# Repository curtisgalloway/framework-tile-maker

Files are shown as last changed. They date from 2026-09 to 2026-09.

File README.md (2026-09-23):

# tilegen



Turn any SVG or image into Framework Desktop front-panel tiles, as multi-color
parts ready to slice. One tile or all 21, with artwork split across the grid.

---

## Use it now

### → **[curtisgalloway.github.io/framework-tile-maker](https://curtisgalloway.github.io/framework-tile-maker/)**

Drop in an SVG or a photo, press **Generate**, download the `.3mf`, open it in
Bambu Studio. Nothing to install, nothing to clone, and nothing is uploaded —
the whole pipeline runs in your browser tab.

[Help and options](https://curtisgalloway.github.io/framework-tile-maker/webjs/help.html)
covers every control.

---

## Running it yourself

Only needed if you want to modify it or work offline:

```bash
git clone --recurse-submodules https://github.com/curtisgalloway/framework-tile-maker.git
cd framework-tile-maker
python3 -m http.server 8790        # any static file server will do
```

Then open <http://127.0.0.1:8790/webjs/>. Cloned without
`--recurse-submodules`? Run `git submodule update --init`.

## What comes out

| File | What it is |
|---|---|
| `NAME.3mf` | Both parts as one object, filaments already assigned. **Use this.** |
| `NAME_body.stl` | Tile with the artwork pocketed out |
| `NAME_ink_1_#RRGGBB.stl` | The insert that fills the pocket exactly |
| `NAME_preview.png` | What the panel surface will look like, before you print |

Body and inserts share the exact same boundary surface — no gap, no overlap.
The two reconstruct the original tile to within 2 × 10⁻⁵ mm³.

---

## Recipes

| Want | Do |
|---|---|
| Logo on one tile | leave the grid at 1 × 1, margin 2.5 |
| One image across the whole panel | click **use it** (3 × 7, margin 0, fit cover) |
| A 2 × 2 block | columns 2, rows 2, fit contain |
| Photo in four colours | pick a JPG, colors 4, fit cover |
| Two-colour logo, one colour as the tile | leave background on `auto` |
| Deeper inlay for white-on-black | depth 1.0 |
| Every tile, even blank ones | leave **blank tile for every empty cell** ticked |

## Options worth knowing

- `--depth 0.6` — inlay depth. 0.6 mm is 3 layers at 0.2 mm, opaque with most
  filaments. Past **1.6 mm** the pocket breaks into the retention hook cut-outs;
  the tool warns you.
- `--background auto` — the color around the outside of the artwork becomes
  the bare tile body instead of a printed color. Saves a filament and all its
  purge. Works for SVGs as well as images: a two-colour logo on a full-bleed
  backdrop prints as a tile in the backdrop colour with one inlaid colour on
  it, rather than two inlays. `--background none` to print it anyway, or
  `--background '#ffffff'` to name it. It never drops the only colour in the
  artwork.
- `--colors N` — how many colors to quantize an image to. Region 1 becomes
  filament 2, region 2 becomes filament 3, and so on.
- `--fit contain | cover | stretch` — `contain` fits the whole artwork inside
  the grid, `cover` fills the grid and crops, `stretch` distorts to fit.
- `--margin` — keep-out from each tile edge. Use `0` for multi-tile artwork so
  it runs across the seams; use `2` or `3` for a single centered logo.
- `--nozzle 0.4` — drives the thin-feature warnings.
- `--min-gap 0.6` — widens any body-colored gap narrower than this by trimming
  the ink beside it; wider gaps are untouched, `0` turns it off. Set it to your
  slicer's first-layer line width plus a little: the art prints face down, so
  every gap is on the first layer, and one narrower than a line fills with ink.
- `--base blank|horizontal|cross|grid|frame` — which tile base to carve into.
  `blank` is the solid face and the default. The others have **open faces**:
  artwork over an opening has no material to carve, so it does not print
  there, and what remains is split into one fragment per opening (28 of them
  for the example logo on `cross`). That is the effect you are asking for, but
  fragments narrower than the mesh tolerance can come out non-watertight —
  slice-check before a long print.
- `--mirror` — only if you print the tile face-up. See *Orientation* below.
- `--embed-filaments` — write the colors into the 3MF, so the slicer opens
  with them assigned instead of bare slot numbers. Ink colors come from the
  artwork. Pair with `--body-color '#2f2f31'` to name the spool you'll load
  for the tile body (filament 1), and `--filament-type PETG` to record the
  material. Off by default: it adds a `project_settings.config`, which is
  project-scoped, so the default output stays exactly as it was.

---

## Printing on the H2D

- **Print face down.** The model already sits that way: the decorated face is
  at z=0, the retention hooks rise in +z. The artwork lands in the first few
  layers against the build plate, which gives the crispest color boundary and
  a smooth finish.
- **Two colors, two nozzles.** Assign body and ink to separate nozzles and the
  H2D swaps without a purge tower. Three or more colors pulls from an AMS and
  purges normally.
- **Body is filament 1.** Inks are 2, 3, 4… in the order printed in the console.
- The tile is 28.5 mm square; 21 of them fit a 256 mm plate in one go.

---

## Why these numbers

- **Pitch 28.60 mm.** Measured from Framework's own released CAD
  (`Tiles/fw_desktop_front_cover.stl`): the tile openings step by exactly 28.60
  in both axes. Several community projects use 28.5, which drifts ~0.6 mm over
  seven rows. Override with `--pitch`.
- **The whole tile face is visible.** At the depth where the tile face sits, the
  cover has no material anywhere across the grid — the 20.9 mm openings deeper
  in are for the retention hooks, not a window over the face. Adjacent tiles
  meet with a ~0.15 mm seam, so artwork runs across tile boundaries nearly
  unbroken.
- **Orientation.** The decorated face is seen from −z, where screen-right is −X
  and screen-down is −Y. That makes the image-to-tile mapping a 180° rotation,
  not a mirror, so artwork is never reversed. Verified by sectioning the
  finished mesh and rendering it from outside.
- **One color, one filament, across every tile.** A tile only carries the
  colors whose artwork reaches it, so the filament slot has to be assigned
  from the full color list before tiles are cut, not from what each tile
  happens to contain. Numbering per tile makes three different colors all come
  out as filament 2 and a three-color panel slices as one color, silently.
  the test suite prints three colored bands across a 3 × 1 grid and asserts
  distinct colors get distinct filaments.
- **Fill rule.** SVG `fill-rule="nonzero"` is honored by computing winding
  numbers, not approximated with even-odd. Get this wrong and counters — the
  inside of an "o", the eye of a spiral — fill in solid. Checked against a
  reference render at IoU 0.996.
- **The artwork canvas is not `cols x pitch`.** Outer tiles contribute only
  their face, and every tile loses `margin` at each edge, so the canvas is
  `(cols-1)*pitch + face - 2*margin`. Sizing to `cols*pitch` overscales by
  `(pitch - face) + 2*margin` and silently crops the artwork — at `--margin 2.5`
  on a single tile that is 18%. The tool reports any real crop.

---

## Credits

**`tile_base.scad` is the work of Marcin Raczkowski (Marmot.Tech)**, licensed
**CC BY-SA 4.0**, from <https://github.com/jermicide/desktoptiles>. No copy of
it lives in this repository — it is vendored unmodified as a git submodule at
`vendor/desktoptiles`, pinned to an upstream commit. All tile body geometry —
the frame, the retention hooks, the constraints, the raised edges, the hook
cut-outs that make the slicer build proper walls — is his. `tilegen` only adds
artwork to it.

His tile follows Framework's published spec,
[`FRAMEWORK_DESKTOP_BLANK_TILE_V0.pdf`](https://github.com/FrameworkComputer/Framework-Desktop/blob/main/Tiles/),
and the panel pitch used here was measured from Framework's
`Tiles/fw_desktop_front_cover.stl` in the same repository.

**Because `tile_base.scad` is CC BY-SA 4.0, tiles produced by this tool are
derivative works.** If you publish or share them, credit Marmot.Tech and
license alike.

---

## Licensing

Two licenses apply here, to different things. The short version: **the code is
Apache 2.0, the tile geometry is CC BY-SA 4.0, and anything you print carries
the CC BY-SA obligations.**

| | License | Why |
|---|---|---|
| `webjs/`, `bases/render.sh` | Apache 2.0 | Original work, © 2026 Curtis Galloway |
| `vendor/desktoptiles/` | CC BY-SA 4.0 | Marcin Raczkowski's repo, vendored as a submodule. Not ours, and not copied into this one |
| `assets/tile_base.stl` | CC BY-SA 4.0 | A render *of* his `tile_base.scad`, so it inherits his license |
| `examples/*.stl`, `examples/*.3mf` | CC BY-SA 4.0 | Same — they contain his tile body |
| **Tiles you generate** | **CC BY-SA 4.0** | Every tile embeds his frame, hooks and constraints |

### What that means in practice

**Using the tool, keeping the tiles to yourself:** nothing to do.

**Publishing or selling tiles you generated** — on Printables, MakerWorld, Etsy,
anywhere: they are derivative works of `tile_base.scad`, so CC BY-SA 4.0
requires you to

1. credit **Marcin Raczkowski (Marmot.Tech)** and link
   <https://github.com/jermicide/desktoptiles>,
2. license the tiles themselves under CC BY-SA 4.0, and
3. say the work was modified.

The [help page](https://curtisgalloway.github.io/framework-tile-maker/webjs/help.html#credits) has text you can paste.

**Reusing tilegen's code** in your own project: Apache 2.0, so keep the notice
and go ahead. Note that Apache 2.0 covers only the code — the moment your
project renders a tile, the output is CC BY-SA again.

**Why not one license for everything?** Apache 2.0 and CC BY-SA 4.0 are not
compatible in either direction, so they cannot be merged — the tile base could
not be relicensed Apache even in principle, since it isn't ours to relicense.
Keeping them separate is what makes the boundary honest: the submodule means
his file is never copied here, and the table above says exactly which artifacts
inherit which terms. `NOTICE.md` records the same thing in one place.

---

## How it is tested

`webjs/tests/run.py` runs 48 checks in headless Chrome against the real
modules — no mocks, no reimplementation. It needs Python only as a process
launcher; there are no third-party packages at all.

The strongest checks are invariants rather than comparisons: body and ink must
reconstruct the base tile to within 2 × 10⁻⁵ mm³, every mesh must be
watertight, each colour must hold one filament slot across every tile, and the
thin-feature warnings must fire on artwork below the nozzle and stay quiet
above it.

The recorded per-tile volumes in `webjs/tests/expected.json` were derived from
a Python implementation that used to live in this repo, and are kept as a
frozen regression snapshot. See `webjs/tests/README.md`.

## The preview shows the real surface

`NAME_preview.png` is drawn from the actual base mesh, not a square: the face
is sliced just above z=0, so the openings in `grid`, `cross`, `horizontal` and
`frame` appear as openings, and artwork is clipped to the material that is
really there. On an open-faced base you can see at a glance which parts of
your artwork survive and which fall into a gap and never print.

## Tile bases

| `--base` | Face | Volume |
|---|---|---|
| `blank` | solid | 1967.63 mm³ |
| `grid` | crossed stripes | 1688.94 mm³ |
| `cross` | diagonal stripes | 1451.97 mm³ |
| `horizontal` | horizontal stripes | 1438.11 mm³ |
| `frame` | none — border only | 1028.20 mm³ |

All five are watertight closed solids, and the test suite checks that, their
dimensions, and that body + ink still reconstructs whichever base was chosen.

They are built by `bases/tilegen_bases.scad`, which `include`s the vendored
`tile_base.scad` unmodified and composes its modules — the extension point
that file's own usage comment documents. Two things made a wrapper necessary
rather than just passing `tile_type`:

- **`tile_base.scad`'s own `crosshatch_fill` clips its stripes to exactly
  `inner_size`**, the same square the frame's inner edge sits on. At angle 0
  the stripes meet that edge squarely and the union is clean; at any other
  angle the slanted ends graze the frame corners with zero-area contact and
  OpenSCAD emits a non-manifold mesh — under *both* backends, at every hatch
  angle and thickness tried. The wrapper runs the stripes past `inner_size` so
  they meet the frame volumetrically.
- **The hook cut-outs are themselves at 45° + 90n.** Stripes at 45° are
  coplanar with the faces being subtracted, which is non-manifold again.
  Measured watertight at 30° and 60°, non-manifold at 15°, 22.5°, 45° and
  67.5°, so the stripe angle defaults to 30°.

---

## Regenerating the tile bases

The five base STLs in `assets/` are committed and the app loads them directly,
so you should not need this. It exists so the bases stay derivable from Marcin
Raczkowski's CC BY-SA source rather than being opaque binaries.

```bash
git submodule update --init      # needs the vendored .scad
./bases/render.sh                # needs OpenSCAD on PATH
```

`bases/render.sh` documents the two non-obvious flags: OpenSCAD's default
Manifold backend exports these bases as meshes that do not close into solids,
so CGAL is requested explicitly; and the stripe angle avoids 45°, where the
stripes go coplanar with the hook cut-outs.

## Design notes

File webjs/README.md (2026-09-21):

<!--
SPDX-FileCopyrightText: 2026 Curtis Galloway
SPDX-License-Identifier: Apache-2.0
-->

# tilegen in the browser

The default way to use tilegen: the whole pipeline in a tab, with no Python,
no server and no install. SVG and raster both work.

```bash
python3 -m http.server 8790 --directory ..   # any static server will do
open http://127.0.0.1:8790/webjs/
```

Nothing is uploaded. The page fetches `../assets/tile_base.stl`, pulls
Manifold's WASM from a CDN, and does everything else locally.

## Does it produce the same tiles?

Measured against the Python on `examples/fuchsia.svg`, one tile, margin 2.5:

| | Python | Browser |
|---|---|---|
| body volume | 1849.1714 mm³ | 1849.1506 mm³ (0.0011% off) |
| ink volume | 118.4562 mm³ | 118.4771 mm³ (0.0176% off) |
| both watertight | yes | yes |
| body + ink vs base | +0.000018 mm³ | **+0.000018 mm³** |
| 3MF entries / objects / extruders | 4 / 3 / 1,2 | 4 / 3 / 1,2 |

The reconstruction figure is the one that matters, and it is identical to the
the Python's to every digit its suite printed. The volume deltas are curve
flattening — the browser samples paths through `getPointAtLength`, svgelements
computes them analytically — and 0.02% is orders of magnitude below what a
0.4 mm nozzle resolves.

A 3 × 7 panel produces 21 objects with no missing cells, and the 3MF passes a
CRC check as a zip.

## Why it is so little code

Two things carry it:

- **Manifold ships the same engine as WASM.** `manifold3d` in Python and
  `manifold-3d` on npm are the same C++ project, so the mesh booleans are not
  a reimplementation, they are the same code.
- **`CrossSection` is Clipper2 with fill rules built in.** That replaces both
  shapely *and* a hand-rolled nonzero winding-number partition —
  `new CrossSection(contours, 'NonZero')` is the whole of it.

The browser itself replaces svgelements: every shape is an
`SVGGeometryElement`, so `getPointAtLength` flattens béziers and arcs exactly
as the renderer would, `getComputedStyle` resolves fill through CSS and
inheritance, and `getCTM` bakes in nested transforms.

## What had to be written by hand

- **Subpath splitting** (`svgload.js`). The DOM will not hand back individual
  subpaths, and the fill rule is defined over them — an `o` whose counter is a
  second subpath must arrive as two rings. Hence a path tokenizer.
- **STL welding** (`stl.js`). An STL is a triangle soup; Manifold's
  constructor throws on anything that is not an oriented 2-manifold.
- **Zip** (`threemf.js`). `CompressionStream('deflate-raw')` is exactly what a
  zip entry wants, so this is a CRC table and a few headers, no library.

## Warnings

The thin-feature and crop warnings are ported. They tell you a logo will not
survive the nozzle before you print it, which is the whole point of them.

The reported PERCENTAGES differ from the CLI's by a few points and are not
tuned to match. shapely offsets through GEOS, this goes through Clipper2, and
the miter limit dominates the difference: on the example logo at an
exaggerated 2 mm nozzle, ink loss reads 25.8% at miter limit 2 and 13.1% at
100, against the CLI's 17%. Fitting a limit to match on one input would be
wrong on the next. Both use the same parameter shapely defaults to (5.0), and
at realistic nozzle sizes they agree on the thing that matters -- whether to
warn at all. On a 3x7 panel at 0.4 mm both emit exactly one warning.

## Not ported

- `--rotate`, `--bleed`, `--scale`, `--invert`, `--plate-origin`.
- `--rebuild-base`, which needs OpenSCAD and so is inherently a CLI job.

## Tests

`python3 webjs/tests/run.py` runs 48 checks in headless Chrome against the
real modules. See `webjs/tests/README.md`.

It earned its place on the first run by catching a real bug: `resolveOverlaps`
had never been ported, so quantized raster regions overlapped on their shared
boundary and were extruded twice.

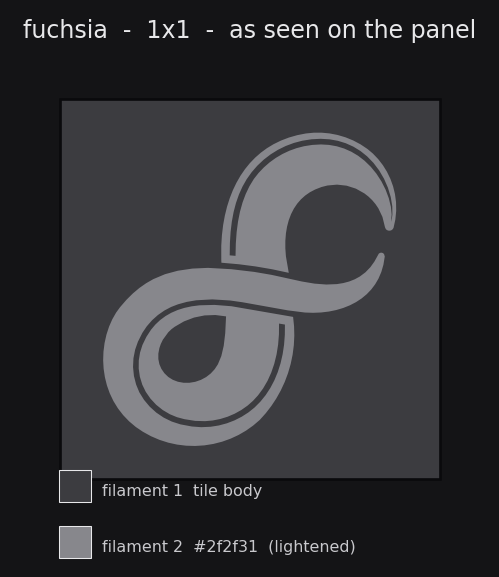
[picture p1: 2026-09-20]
examples/fuchsia_preview.png

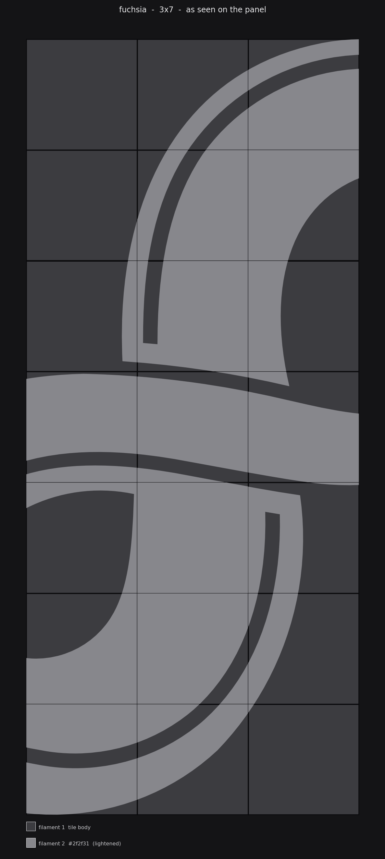
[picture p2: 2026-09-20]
examples/panel_3x7/fuchsia_preview.png

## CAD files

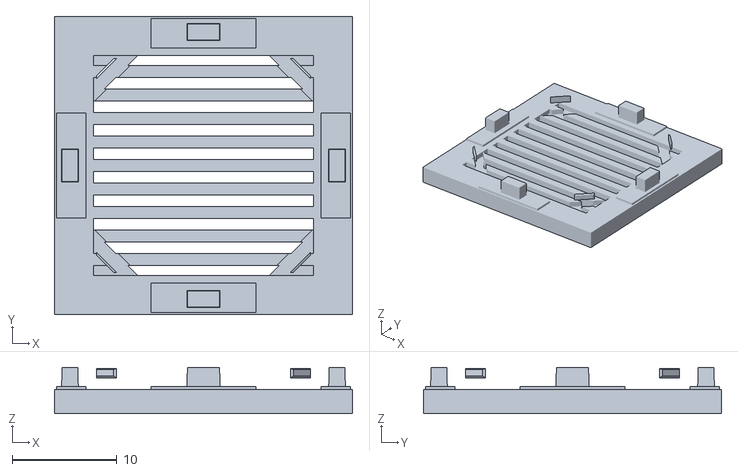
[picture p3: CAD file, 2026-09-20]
assets/tile_base_horizontal.stl
28.5 x 28.5 x 4.40

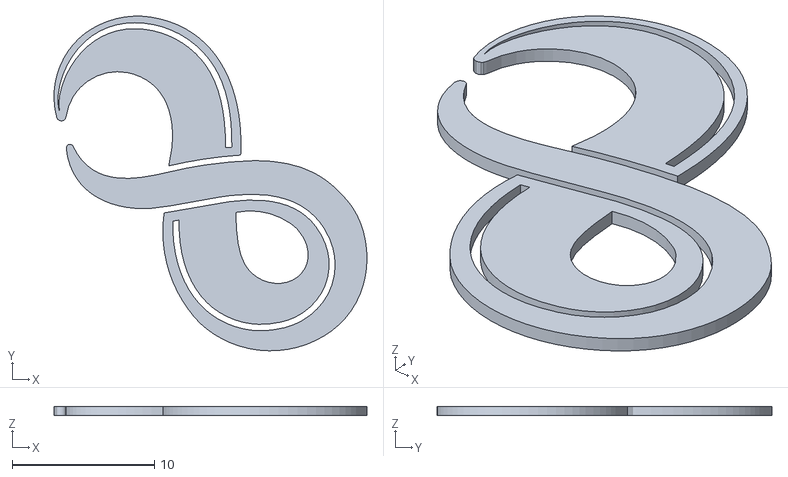
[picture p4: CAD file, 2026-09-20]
examples/fuchsia_ink_1_#2f2f31.stl
22.0 x 23.5 x 0.6

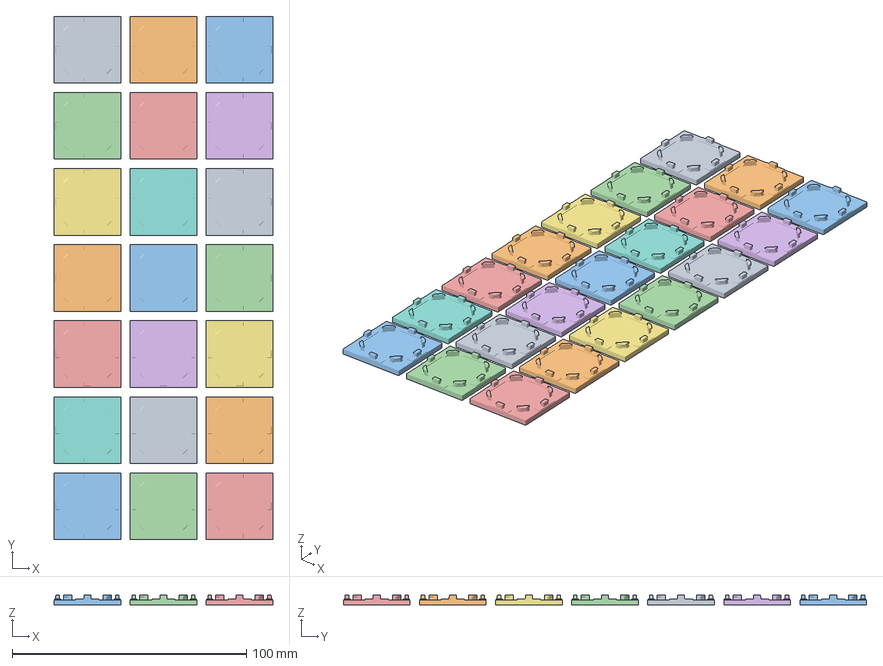
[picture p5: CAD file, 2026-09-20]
examples/panel_3x7/fuchsia_3x7.3mf
93.5 x 223.5 x 4.40 mm
fuchsia_r0c0
fuchsia_r0c1
fuchsia_r0c2
fuchsia_r1c0
fuchsia_r1c1
fuchsia_r1c2
fuchsia_r2c0
fuchsia_r2c1
fuchsia_r2c2
fuchsia_r3c0
fuchsia_r3c1
fuchsia_r3c2
fuchsia_r4c0
fuchsia_r4c1
fuchsia_r4c2
fuchsia_r5c0
fuchsia_r5c1
fuchsia_r5c2
fuchsia_r6c0
fuchsia_r6c1
fuchsia_r6c2

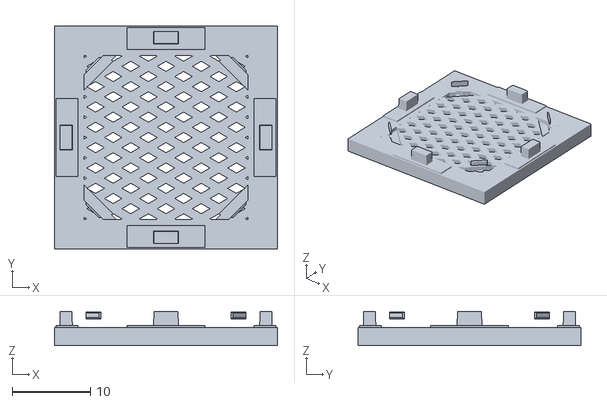
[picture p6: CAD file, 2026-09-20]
assets/tile_base_grid.stl
28.5 x 28.5 x 4.40

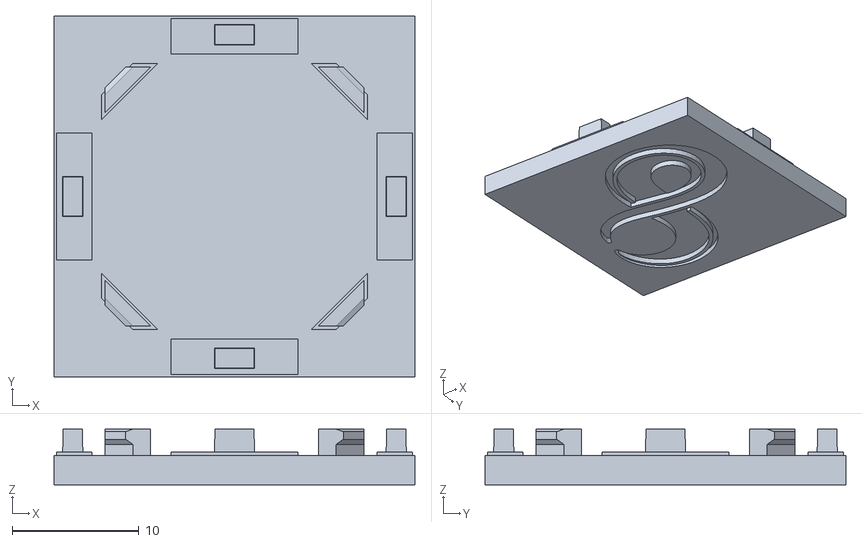
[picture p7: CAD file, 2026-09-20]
examples/fuchsia_body.stl
28.5 x 28.5 x 4.40

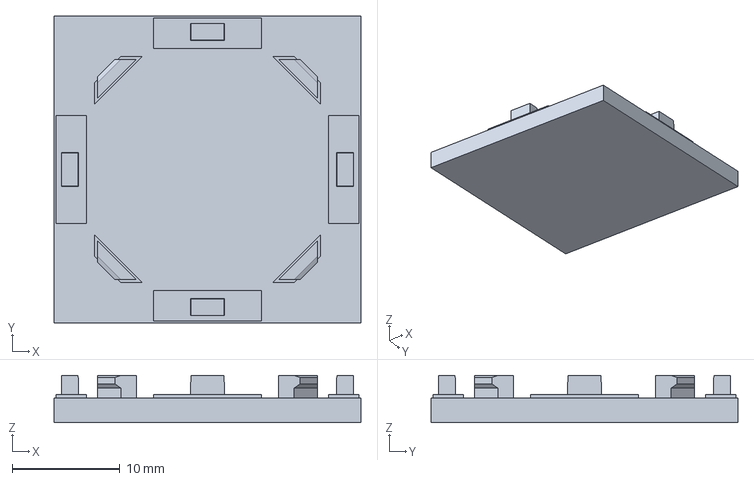
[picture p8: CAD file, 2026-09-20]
examples/fuchsia.3mf
28.5 x 28.5 x 4.40 mm

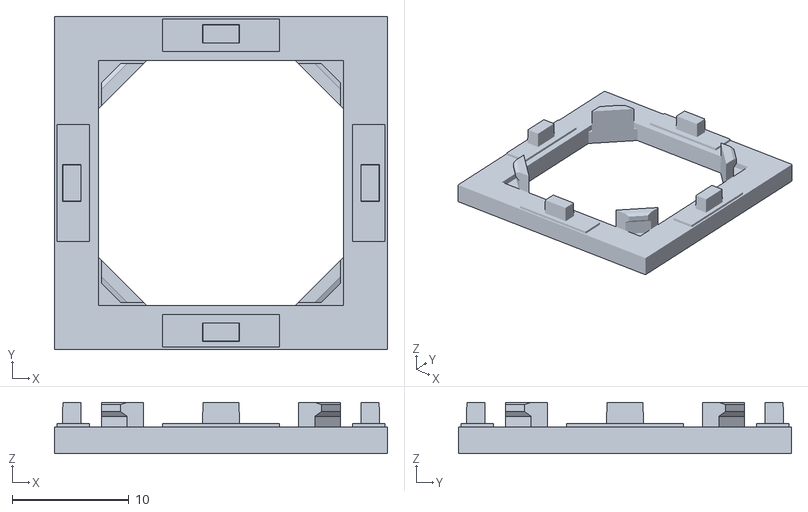
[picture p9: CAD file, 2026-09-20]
assets/tile_base_frame.stl
28.5 x 28.5 x 4.40

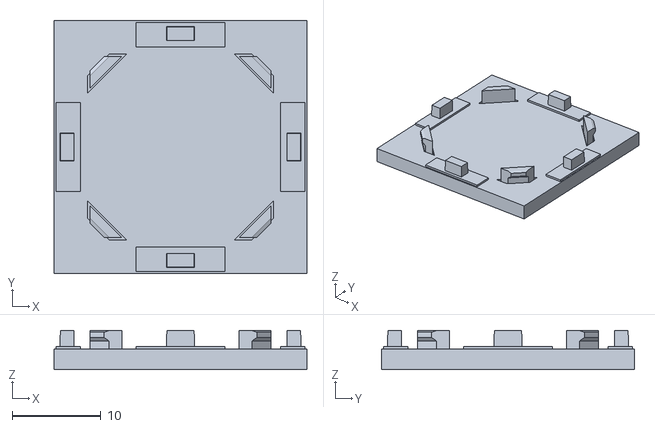
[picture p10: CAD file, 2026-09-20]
assets/tile_base.stl
28.5 x 28.5 x 4.40

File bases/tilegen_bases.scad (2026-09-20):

// SPDX-FileCopyrightText: 2026 Curtis Galloway
// SPDX-License-Identifier: Apache-2.0
//
// Extra tile bases for tilegen, built on Marcin Raczkowski's tile_base.scad
// (CC BY-SA 4.0, vendor/desktoptiles). That file is included unmodified and
// its modules are composed here, which is the extension point its own usage
// comment documents:
//
//     include <tile_base.scad>
//     tile_type = "none";
//     union() { full_frame(); my_design(); }
//
// Rendered tiles remain derivative works of his file -- see NOTICE.md.
//
// Why this file exists at all: tile_base.scad's own crosshatch_fill clips its
// stripes to exactly inner_size, the same square the frame's inner edge sits
// on. At angle 0 the stripes meet that edge squarely and the union is clean,
// but at any other angle the slanted ends graze the frame corners with
// zero-area contact and OpenSCAD emits a non-manifold mesh -- confirmed under
// both the CGAL and Manifold backends, at hatch angles 30/40/44/45/46 and
// thicknesses 0.8 through 2.0. The fix is not a parameter: it is to let the
// stripes run PAST inner_size so they meet the frame volumetrically.

include <../vendor/desktoptiles/tile_base.scad>

// Suppress the included file's own top-level output; we compose it ourselves.
tile_type = "none";

// How far the fill runs into the frame. Anything comfortably larger than a
// rounding error works: the overlap is buried inside frame material, so it
// changes nothing you can see or print.
tg_overlap = 0.5;

/* [tilegen] */
// Which base to render
tg_base = "blank"; // ["blank", "frame", "horizontal", "cross", "grid"]
// Stripe width [mm]
tg_thickness = 1.125;
// Stripe angle [deg]. NOT 45: the hook cut-outs are themselves at 45 + 90n
// degrees, so 45-degree stripes end up coplanar with the faces being
// subtracted and the result is non-manifold. Measured watertight at 30 and 60,
// non-manifold at 15, 22.5, 45 and 67.5.
tg_angle = 30;

module tg_stripes(angle, thickness) {
  span = inner_size + 2 * tg_overlap;
  n = ceil(inner_size / thickness / 2) + 2;
  linear_extrude(front_thickness) intersection() {
    square(span, center = true);
    union() for (i = [-n : n])
      rotate([0, 0, angle])
        translate([0, thickness * 2 * i])
          square([inner_size * 3, thickness], center = true);
  }
}

// The hook cut-outs must be taken out of the finished solid, not out of the
// fill alone: a stripe that now overlaps the frame would otherwise re-fill
// the cut-out the frame just made.
module tg_tile(fill_angle, thickness, striped = true, crossed = false) {
  difference() {
    union() {
      mounts();
      linear_extrude(frame_thickness)
        difference() {
          square(tile_size, center = true);
          square(inner_size, center = true);
        }
      if (striped) {
        tg_stripes(fill_angle, thickness);
        if (crossed) tg_stripes(-fill_angle, thickness);
      }
    }
    hook_cutout();
  }
}

if (tg_base == "blank") {
  blank_tile();
} else if (tg_base == "frame") {
  full_frame();
} else if (tg_base == "horizontal") {
  tg_tile(0, tg_thickness);
} else if (tg_base == "cross") {
  tg_tile(tg_angle, tg_thickness);
} else if (tg_base == "grid") {
  tg_tile(tg_angle, tg_thickness, striped = true, crossed = true);
}

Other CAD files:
assets/tile_base_cross.stl

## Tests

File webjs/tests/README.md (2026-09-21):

<!--
SPDX-FileCopyrightText: 2026 Curtis Galloway
SPDX-License-Identifier: Apache-2.0
-->

# Browser tests

48 regression checks. The browser modules run for real in headless Chrome.

```bash
python3 webjs/tests/run.py              # non-zero exit on failure
python3 webjs/tests/run.py --headed     # watch it in a visible browser
```

stdlib only — no pip install, no npm.

Open `/webjs/tests/` in any browser to run the same suite by hand.

## Why a real browser

The SVG loader uses the browser's own SVG engine on purpose — `getPointAtLength`
flattens curves exactly as the renderer would — and the raster path uses canvas.
jsdom implements neither, so headless Chrome is the only honest harness. The
runner starts a static server, launches Chrome, and the page POSTs its results
back; stdlib only, no npm.

## expected.json is a frozen snapshot

These were derived from the Python reference implementation that used to live
in this repo, and were correct against it when recorded. That implementation
has been removed, so they are now **golden values**: a failure means the
browser's behaviour changed, which is what a regression suite is for — but no
longer that it disagrees with an independent implementation.

Several checks never needed the reference and are the stronger ones: body+ink
reconstructing the base to 0.00002 mm³, watertightness, distinct filament slots
per colour, and whether the thin-feature warnings fire. Those are invariants,
and they would catch a real geometry regression with every recorded number
deleted. It is the per-tile volume comparisons that lost their independence.

## Tolerances, and why they differ

| | Tolerance | Why |
|---|---|---|
| single tile, SVG | 0.05 mm³ | same kernel, same contours; agrees to ~0.02 |
| reconstruction | 0.001 mm³ | exact: a boolean partition cannot drift |
| 3×7 panel | 0.15 mm³ | flattening error scales with artwork size |
| raster, smooth | 1% | recorded against a different tracer; measures 0.03% |
| raster, noise | 8% | see below |

The noise fixture is 160 px of high-frequency speckle. Every blob is a few
pixels across, so marching squares placing its isoline on the half-pixel
boundary shifts a large perimeter relative to a small area, and the two tracers
land ~4.6% apart. That is inherent to the fixture, not a defect — which the
smooth fixture proves by agreeing to 0.03% on the same code path. So the noise
fixture asserts *survival and self-consistency* rather than agreement.

The exact assertion there — body + ink reconstructing the base — is what caught
the missing `resolveOverlaps`: quantized regions are disjoint by pixel, but
their contours are traced independently, so neighbours both claimed the
boundary strip and the overlap was extruded twice (+2.22 mm³). Verified to
still bite: removing `resolveOverlaps` fails that check and only that check.

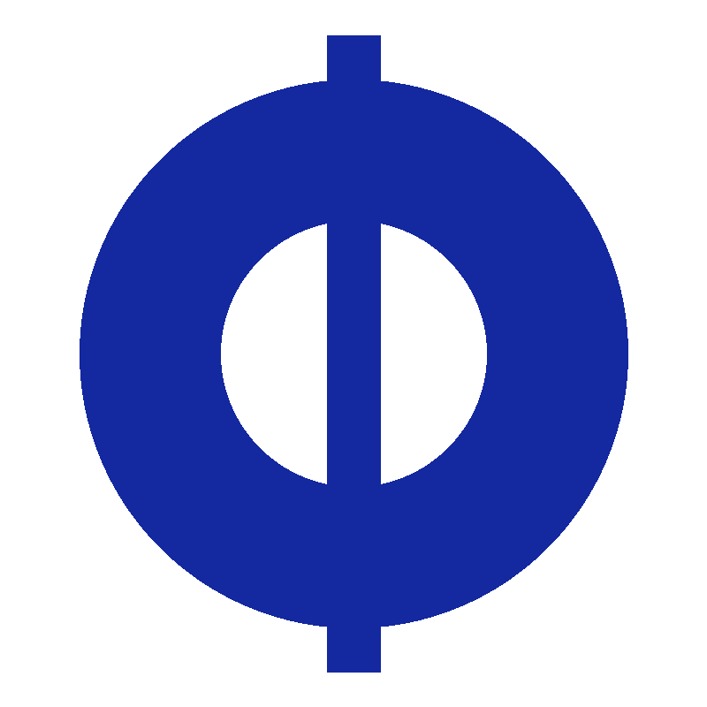
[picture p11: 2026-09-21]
webjs/tests/fixtures/blobs.png

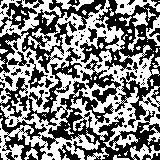
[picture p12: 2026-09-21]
webjs/tests/fixtures/noise.png

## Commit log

2026-09-20 Initial commit: tilegen, with the tile base as a submodule
    tilegen turns any SVG or raster image into Framework Desktop front-panel
    tiles, split across a tile grid, as multi-colour parts ready to slice.
    The tile body geometry is tile_base.scad by Marcin Raczkowski (Marmot.Tech),
    CC BY-SA 4.0. Rather than carry a copy of that file, this repository vendors
    his repository unmodified as a git submodule at vendor/desktoptiles, pinned
    to upstream commit 319c5f80cd4df2b0f6d9d86f9a9e27ef80d1212a. Nothing of his
    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
    [fuchsia.3mf, fuchsia_3x7.3mf, fuchsia_body.stl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]
2026-09-20 Fix --rebuild-base and the selftest deps; add Apache 2.0 licensing
    Three fixes, none of them caused by the submodule conversion -- all three
    were latent and only surfaced when the tool was exercised end to end.
    --rebuild-base produced an unusable tile base
    ---------------------------------------------
    OpenSCAD now defaults to the Manifold backend, which exports this model as
    472 facets that do not close into a solid (the hook cut-outs come out with
    unmerged vertices). trimesh's boolean engine then refuses it with "Not all
    meshes are volumes!" and the run dies. The cached assets/tile_base.stl that
    ships here was rendered by CGAL, which is why it was fine and a fresh render
    was not.
    ensure_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
2026-09-20 Web UI: keep blank tiles by default, and report the tile count
    Reported: a downloaded 3MF was missing tiles -- one from a 3x7, two from a
    3x3. Reproduced exactly: the 3x3 wrote "(7 object(s))" with r0c0 and r2c2
    absent.
    Nothing was dropping them. tilegen skips a cell the artwork never reaches
    unless --keep-empty, and the web UI left that checkbox off, so a panel came
    back with holes where the corners were blank. That is a reasonable CLI default
    -- you may only want to print the tiles that carry artwork -- but it is the
    wrong default for a panel, which needs all 21 tiles to be physically complete,
    and the loss was invisible among 40 filenames.
    The checkbox now defaults on, and the results p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
2026-09-20 Set filament colors in the 3MF, and fix per-tile extruder numbering
    Two changes, the second found while building the first.
    Filament colors in the 3MF
    --------------------------
    Yes, this is possible, and it is not in model_settings.config. Filament COLOR
    is project scope: model_settings carries only the slot number ("this part is
    filament 2") and has no color key at all -- checked against every metadata key
    a real multi-color Bambu project on disk uses. The color lives in
    Metadata/project_settings.config as "filament_colour", an array of hex strings
    indexed from filament 1.
    A slicer-saved project writes ~557 keys there, but Bambu does not need them:
    loading a tilegen 3MF carrying only fi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
2026-09-20 Web UI: explicit checkbox for the body color, not a blank field
    "Leave blank to mean unset" was poor UI: the field gave no hint that empty was
    a meaningful state rather than an unfilled one, and it read as something you
    had forgotten to complete.
    Now "also set the body color (filament 1)" is its own checkbox that reveals
    the picker, and the picker always carries a real value. Off is now something
    you choose rather than something you leave undone, and the two states are
    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
2026-09-20 Spike: run the whole SVG pipeline in the browser, no Python
    Answers the feasibility question with a working thing rather than an opinion.
    Everything runs in a tab: no install, no server, nothing uploaded. Serve the
    repo statically and open /webjs/.
    Measured against the Python on examples/fuchsia.svg, 1 tile, margin 2.5:
    body volume 1849.1714 -> 1849.1506 mm3 (0.0011% off)
    ink volume 118.4562 -> 118.4771 mm3 (0.0176% off)
    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
2026-09-20 Spike: show progress while generating, and refuse re-entry
    Reported: clicking Generate shows nothing, so it invites clicking again.
    The button was already being disabled and relabelled -- but the pipeline then
    occupied the main thread for seconds, and style changes are painted on that
    same thread, so the updates sat queued until the work they were meant to
    describe had finished. A spinner alone would not have fixed it; the run has to
    hand the browser a frame.
    It now yields before each phase and once per tile, so the button state, a
    determinate progress bar and a "tile 11 of 21" label all paint as the work
    happens. The spinner animates transform only, which the compositor owns, so it
    keeps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
2026-09-20 Add selectable tile bases: blank, horizontal, cross, grid, frame
    --base picks what the artwork is carved into. blank is the solid face and
    remains the default; the rest have open faces, which is the point of them.
    The obvious implementation -- pass tile_type to the vendored tile_base.scad --
    does not work, and the reason is worth recording because it looks like a
    parameter problem and is not:
    - tile_base.scad's crosshatch_fill clips its stripes to exactly inner_size,
    the same square the frame's inner edge sits on. At angle 0 the stripes meet
    that edge squarely and the union is clean. At any other angle the slanted
    ends graze the frame corners with zero-area contact and OpenSCAD emits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
    [tile_base_cross.stl, tile_base_frame.stl, tile_base_grid.stl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]
2026-09-20 Fix "Not all meshes are volumes!" on photos; extrude via manifold
    Reported: a JPEG fails. Reproduced with a real photo -- the run dies in
    build_tile with ValueError: Not all meshes are volumes!. SVGs were unaffected,
    which is why this survived this long.
    Two separate problems, both in extrude(), both specific to traced raster
    contours:
    - It built one prism per polygon and CONCATENATED them. That is a triangle
    soup, valid only while the prisms stay apart. Raster contours do not: the
    reported photo quantized to two colors gave 484 polygons with 170 touching
    pairs, and prisms meeting at an edge or a point are not a volume.
    - trimesh.creation.extrude_polygon itself returned non-volumes f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
2026-09-20 Preview the real tile surface, not a square
    Asked whether the preview could show what the tile surface will actually look
    like. It can, and it turned out the preview was already wrong: it drew a solid
    square whatever base was selected, so every open-faced base previewed as a
    blank tile -- a tile that will never be printed.
    The face is now sliced from the base mesh just above z=0 and drawn as it is,
    so the openings in grid, cross, horizontal and frame appear as openings.
    Artwork is clipped to that outline, so what you see is what has material to
    carve: on 'frame' the example logo all but vanishes, leaving only the arc that
    crosses the border, which is exactly what would come off the plate.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
2026-09-21 Browser: tile bases and the real-surface preview
    First step of making the browser version the product: everything main gained
    since the spike, except raster input, which is next.
    All five bases are selectable and loaded on demand from the same cached STLs
    the CLI uses, cached per base so switching back is free. The face is sliced
    from the base mesh with Manifold.slice and drawn as it really is, so openings
    read as openings, and ink is intersected with that outline before extruding --
    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
2026-09-21 Browser: raster input, so the JS version is feature-complete for artwork
    PNG/JPEG/WEBP now work in the tab. This was the last thing only the Python
    could do, and the part with no library to lean on: tilegen.py uses OpenCV for
    Otsu, k-means and findContours, and the browser has none of those.
    webjs/src/raster.js decode, Otsu, k-means, marching squares, ~300 lines
    Choices worth recording:
    - Two colors goes through Otsu, not k-means with k=2. It is faster and far
    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
2026-09-21 Browser: port the thin-feature and crop warnings
    The last valuable gap. These are what tell you a logo will not survive the
    nozzle before you commit to a forty minute print, and the browser was silently
    producing the same unprintable geometry the CLI would have warned about.
    webjs/src/report.js thinReport, featureReport, cropReport
    Both failure modes are covered: ink strokes thinner than the nozzle, and
    body-colored GAPS thinner than the nozzle. The second is the one people do not
    think of -- a logo with fine counters prints as a blob not because the ink is
    too thin but because the spaces between it are.
    Implemented as a morphological opening, the same as the Python: anything that
    can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
2026-09-21 Add a Pages front door and .nojekyll
    The app has to live at /webjs/ because it loads the tile base from
    ../assets/, so the repository root needs something that points at it. A meta
    refresh with a visible link covers both the automatic case and anyone whose
    browser blocks it.
    .nojekyll because nothing here wants Jekyll's processing, and its
    underscore-prefixed-file rule is a trap waiting for a future file name.
2026-09-21 Add a help page, and link it from the app
    The app page now says what it is in one line and links out, rather than
    carrying the explanation itself: a Help and options page covers what comes
    out, every control, printing, and the credits.
    Attribution stays visible on the app page as a single line, because that is
    where tiles actually get made and CC BY-SA asks for credit where the work is
    used. The detail -- what you owe if you publish tiles, and why the two
    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
2026-09-21 Fix a color/geometry mismatch and four WASM leaks, from external review
    All five were found by an outside model through oxbox and confirmed against
    the source before being acted on.
    COLOR ATTACHED TO THE WRONG GEOMETRY (app.js:201, the one that would print
    wrong)
    resolveOverlaps drops a region that a later one completely covers, which
    SHORTENS its result. The caller then did
    sections.map((section, i) => ({section, slot: i, hexColor: regions[i].hex}))
    indexing the FULL regions list by the post-drop position, so every colour
    after a dropped region was attached to the next region's geometry. The
    embedded filament palette was built from the full list too, so the 3MF told
    the slicer to lo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
2026-09-21 Harden the STL parser and XML escaping, from external review
    Second round of confirmed findings. Severity context first, because it bounds
    all of this: parseSTL is only ever fed the five committed assets/tile_base*.stl
    files, by name, from a fixed map. No user-supplied STL can reach it. These are
    robustness fixes in code whose entire input is five files we ship.
    stl.js -- vertex welding could leave a crack
    The weld hashed a 5-decimal quantized key but stored the UN-quantized value,
    and looked in exactly one cell. Two writes of the same physical corner can
    differ in the last float32 bit, and if that difference straddles a cell
    boundary -- 2.500005 keying "2.50001" against 2.500004 keying "2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
2026-09-21 Free the intermediates in pipeline.js; make buildTile's aliasing explicit
    The earlier leak fix (99c814f) tracked what app.js RECEIVES. It did not touch
    what pipeline.js allocates and drops internally, which app.js never sees. Every
    Manifold and CrossSection operation returns a NEW object and WASM memory is not
    garbage collected, so writing them as chains orphans every intermediate:
    fitTransform:139 sec.translate(...).scale(...) -> the translate result
    fitTransform:144 g = g.simplify(tolMm) -> the scale result
    buildTile:232 section.extrude(...).translate -> the extrude result
    fitTransform:111 translate().rotate().translate -> both intermediates
    The first two fir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
2026-09-21 Stop executing user SVGs, and stop inventing regions from invisible geometry
    The most serious finding of the review. loadSVG assigned the user's file
    straight to host.innerHTML on the live document, which RUNS it. Measured in
    Chrome: <image onerror>, <foreignObject><img onerror> and SMIL <set onbegin>
    all fired in the page's origin, and external href values fetch. <script> alone
    does not run, which is exactly what makes the hole easy to miss -- the obvious
    test passes.
    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
2026-09-21 Fix color quantization collapsing on skewed images
    Found by a verifier agent while its oxbox batch sat in the queue -- that batch
    then failed at the venue, so raster.js got no external review at all. This is
    the one real defect anyone found in it, and it is user-reachable: the Colors
    input accepts 2-8 and anything above 2 takes this path.
    k-means seeds were picked by RANK in luminance order:
    order[floor((c + 0.5) * n / k)]
    which selects by position in the sorted list, not by colour. When one colour
    holds more than a 1/k-spaced share of that order -- a logo on a plain
    background, i.e. the normal case -- several seeds land on the SAME pixel.
    Reproduced on a 40x40 image, 76% white with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
2026-09-22 Fix two-color SVGs: keep paint order, keep per-path fill rules
    A two-color logo with a mark drawn in the backdrop color came out wrong in
    two independent ways, both visible against the browser's own rendering of
    the same file.
    Paint order was lost. svgload bucketed every shape by fill color and gave
    each color the position of its FIRST appearance, so a color drawn twice --
    a backdrop, then a mark on top of the other color -- was pinned underneath.
    resolveOverlaps then subtracted the later color from it and the mark
    disappeared: measured on a two-color logo, the dark star drawn last over
    the accent vanished from the tile entirely.
    The fill rule was applied across paths. Every ring of a colo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
2026-09-23 Widen body-color gaps narrower than a settable minimum
    A two-color logo sliced with specks of ink along its dark curves. Those
    curves are body-color gaps between ink pieces, 0.40-0.55 mm wide at tile
    scale. The art prints face down, so every gap lands on the first layer,
    whose default line width on a Bambu 0.4 mm nozzle is 0.5 mm. A gap
    narrower than one line is not laid down cleanly, and the ink on either
    side spills into it. The existing gap warning compares against the nozzle
    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
2026-09-23 Fix min gap falling short on curved gaps
    widenGaps promised that every body gap would reach minGap. On a gap
    curving away from a pinch (two disks 0.1 mm apart, minGap 0.6), the
    narrowest ink-to-ink distance came out at 0.342 mm. Three causes:
    - The width-band test used a Miter opening. Growing the eroded gap back
    with Miter joins pushes its sharp corners into a pinch, so strips
    narrower than the band counted as wide enough and were never widened.
    It now uses Round joins. The report.js warnings keep Miter, where
    flagging every corner would be the wrong answer.
    - The noise filter opened each band by 0.02 mm. That removed the
    hairline residue it was meant to remove, but it also cut t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
